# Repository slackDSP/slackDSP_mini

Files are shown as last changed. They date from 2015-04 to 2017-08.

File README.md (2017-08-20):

# slackDSP_mini

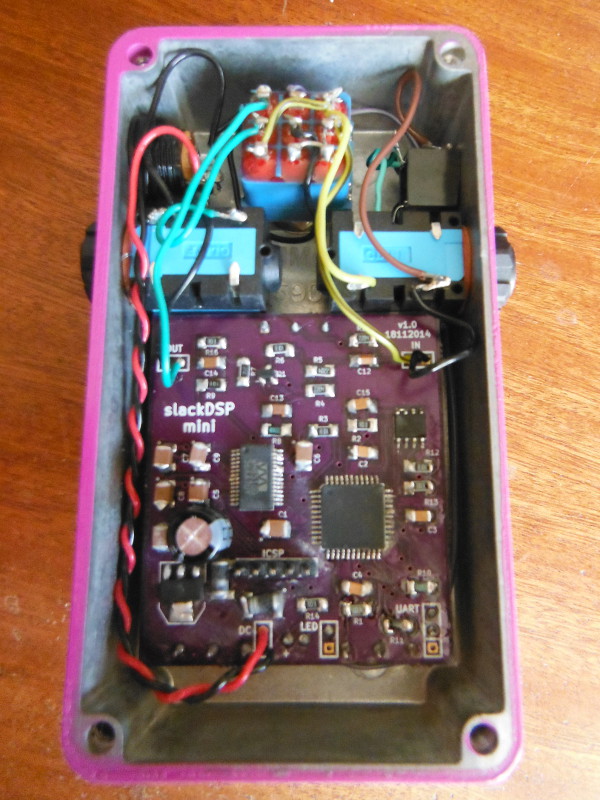
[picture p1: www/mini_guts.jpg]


[YouTube demo video](http://www.youtube.com/watch?v=F_a12EcQlmA)

Nothing to see here yet....

<br>

### Resources
* [dsPIC33FJ128GP804 datasheet](http://ww1.microchip.com/downloads/en/DeviceDoc/70292G.pdf)
* [Wolfson WM8510 datasheet](https://www.cirrus.com/en/pubs/proDatasheet/WM8510_v4.5.pdf)
* [23LC1024 datasheet](http://ww1.microchip.com/downloads/en/DeviceDoc/20005142C.pdf)
* [MPLABX IDE download page](http://www.microchip.com/pagehandler/en-us/family/mplabx/home.html)
* [XC16 compiler download page](http://www.microchip.com/pagehandler/en-us/devtools/mplabxc/home.html)

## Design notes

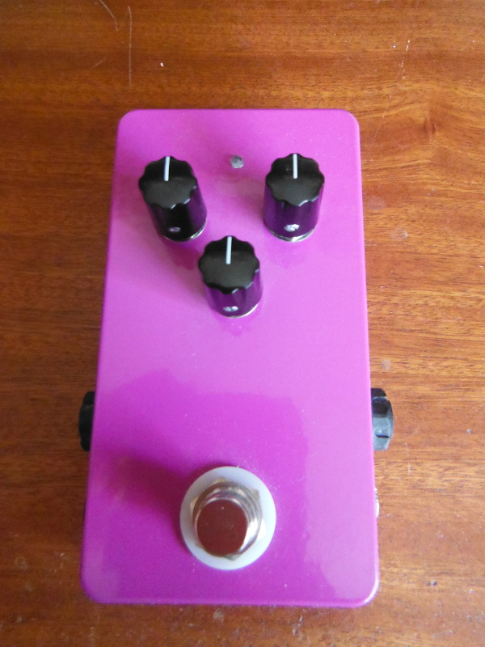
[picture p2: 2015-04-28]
www/mini.jpg

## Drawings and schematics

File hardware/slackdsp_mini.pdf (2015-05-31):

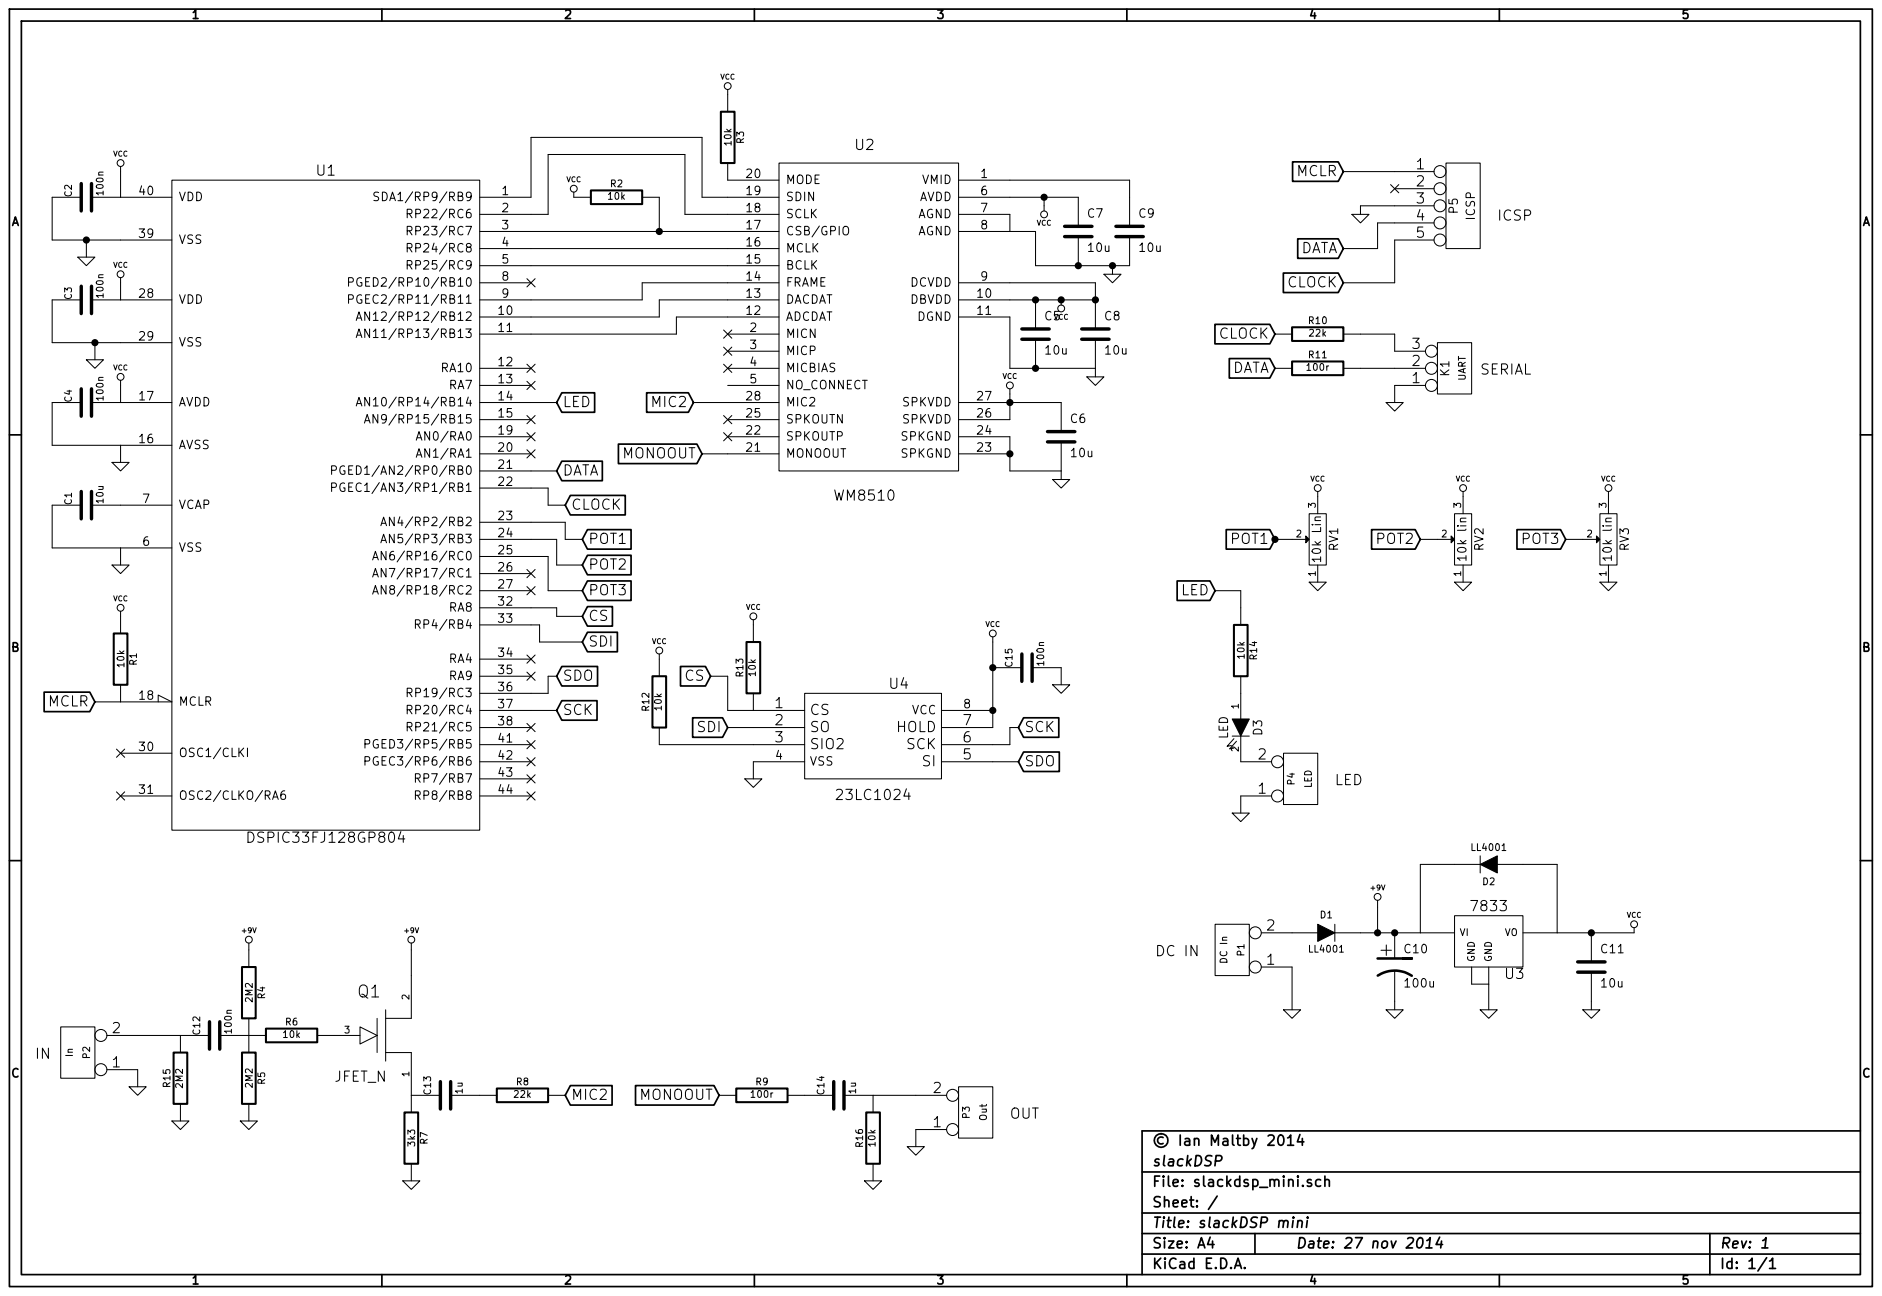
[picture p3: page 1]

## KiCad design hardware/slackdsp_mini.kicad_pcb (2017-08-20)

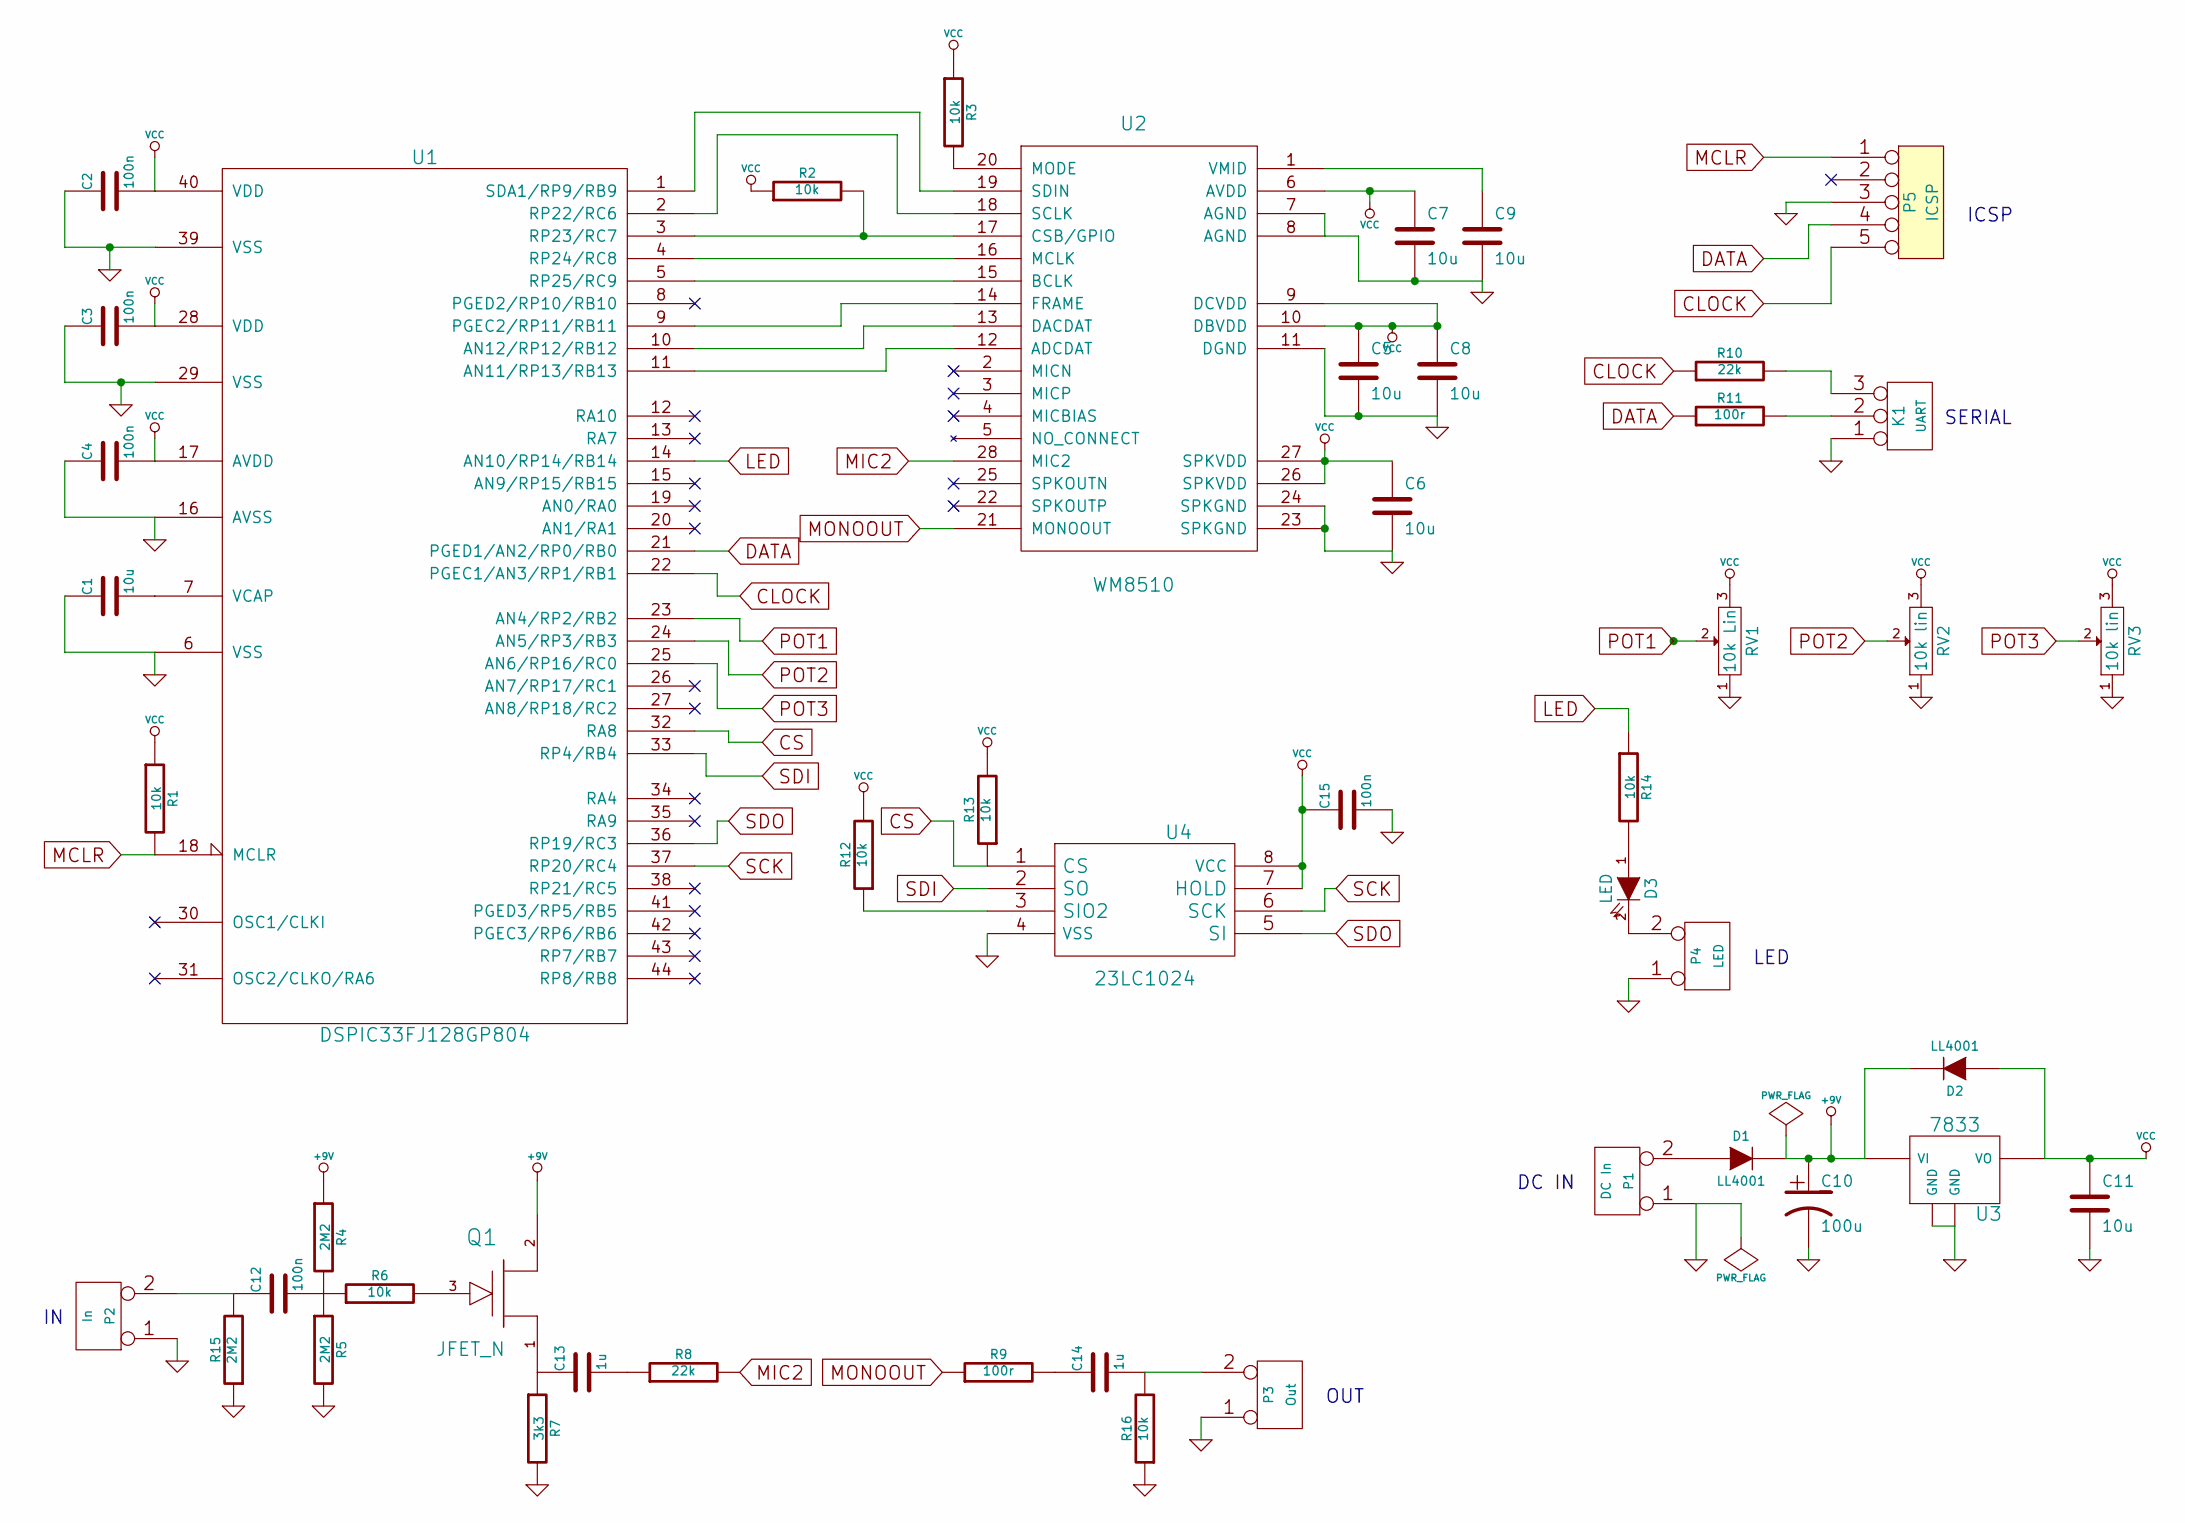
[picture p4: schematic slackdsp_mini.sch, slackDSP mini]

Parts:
C1, C5, C6, C7, C8, C9, C11: 10u; C_1210_HandSoldering
C2, C3, C4, C12, C15: 100n; C_1206
C10: 100u; CP_Radial_D5.0mm_P2.50mm
C13, C14: 1u; C_1206
D1, D2: LL4001; C_1812
D3: LED; LED_D3.0mm
K1: UART; Pin_Header_Straight_1x03_Pitch2.54mm
P1: DC In; Pin_Header_Straight_1x02_Pitch2.54mm
P2: In; Pin_Header_Straight_1x02_Pitch2.54mm
P3: Out; Pin_Header_Straight_1x02_Pitch2.54mm
P4: LED; Pin_Header_Straight_1x02_Pitch2.54mm
P5: ICSP; Pin_Header_Straight_1x05_Pitch2.54mm
Q1: JFET_N; SOT-23
R1, R2, R3, R6, R12, R13, R14, R16: 10k; R_1206
R4, R5, R15: 2M2; R_1206
R7: 3k3; R_1206
R8, R10: 22k; R_1206
R9, R11: 100r; R_1206
RV1: 10k Lin; POT_16mm
RV2, RV3: 10k lin; POT_16mm
U1: DSPIC33FJ128GP804; TQFP-44_10x10mm_Pitch0.8mm
U2: WM8510; SSOP-28_5.3x10.2mm_Pitch0.65mm
U3: 7833; SOT-223
U4: 23LC1024; SO8-Narrow

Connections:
+9V: C10.1, D1.2 (K), D2.2 (K), Q1.2 (D), R4.1, U3.1 (VI)
CLOCK: P5.5, R10.1, U1.22 (PGEC1/AN3/RP1/RB1)
CS: R13.1, U1.32 (RA8), U4.1 (CS)
DATA: P5.4, R11.1, U1.21 (PGED1/AN2/RP0/RB0)
GND: C1.1, C2.1, C3.1, C4.1, C5.2, C6.2, C7.2, C8.2, C9.2, C10.2, C11.2, C15.2, K1.1, P1.1, P2.1, P3.1, P4.1, P5.3, R5.2, R7.2, R15.1, R16.1, RV1.1, RV2.1, RV3.1, U1.6 (VSS), U1.16 (AVSS), U1.29 (VSS), U1.39 (VSS), U2.7 (AGND), U2.8 (AGND), U2.11 (DGND), U2.23 (SPKGND), U2.24 (SPKGND), U3.2 (GND), U3.4 (GND), U4.4 (VSS)
LED: R14.1, U1.14 (AN10/RP14/RB14)
MCLR: P5.1, R1.2, U1.18 (MCLR)
MIC2: R8.2, U2.28 (MIC2)
MONOOUT: R9.1, U2.21 (MONOOUT)
unnamed: C1.2, U1.7 (VCAP)
unnamed: C9.1, U2.1 (VMID)
unnamed: C12.1, P2.2 (PM), R15.2
unnamed: C12.2, R4.2, R5.1, R6.1
unnamed: C13.1, Q1.1 (S), R7.1
unnamed: C13.2, R8.1
unnamed: C14.1, R9.2
unnamed: C14.2, P3.2 (PM), R16.2
unnamed: D1.1 (A), P1.2 (PM)
unnamed: D3.1 (A), R14.2
unnamed: D3.2 (K), P4.2 (PM)
unnamed: K1.2 (PM), R11.2
unnamed: K1.3, R10.2
unnamed: Q1.3 (G), R6.2
unnamed: R2.2, U1.3 (RP23/RC7), U2.17 (CSB/GPIO)
unnamed: R3.2, U2.20 (MODE)
unnamed: R12.1, U4.3 (SIO2)
unnamed: U1.1 (SDA1/RP9/RB9), U2.19 (SDIN)
unnamed: U1.2 (RP22/RC6), U2.18 (SCLK)
unnamed: U1.4 (RP24/RC8), U2.16 (MCLK)
unnamed: U1.5 (RP25/RC9), U2.15 (BCLK)
unnamed: U1.9 (PGEC2/RP11/RB11), U2.14 (FRAME)
unnamed: U1.10 (AN12/RP12/RB12), U2.13 (DACDAT)
unnamed: U1.11 (AN11/RP13/RB13), U2.12 (ADCDAT)
POT1: RV1.2, U1.23 (AN4/RP2/RB2)
POT2: RV2.2, U1.24 (AN5/RP3/RB3)
POT3: RV3.2, U1.25 (AN6/RP16/RC0)
SCK: U1.37 (RP20/RC4), U4.6 (SCK)
SDI: U1.33 (RP4/RB4), U4.2 (SO)
SDO: U1.36 (RP19/RC3), U4.5 (SI)
VCC: C2.2, C3.2, C4.2, C5.1, C6.1, C7.1, C8.1, C11.1, C15.1, D2.1 (A), R1.1, R2.1, R3.1, R12.2, R13.2, RV1.3, RV2.3, RV3.3, U1.17 (AVDD), U1.28 (VDD), U1.40 (VDD), U2.6 (AVDD), U2.9 (DCVDD), U2.10 (DBVDD), U2.26 (SPKVDD), U2.27 (SPKVDD), U3.3 (VO), U4.7 (HOLD), U4.8 (VCC)

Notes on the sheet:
ICSP
SERIAL
OUT
DC IN
LED

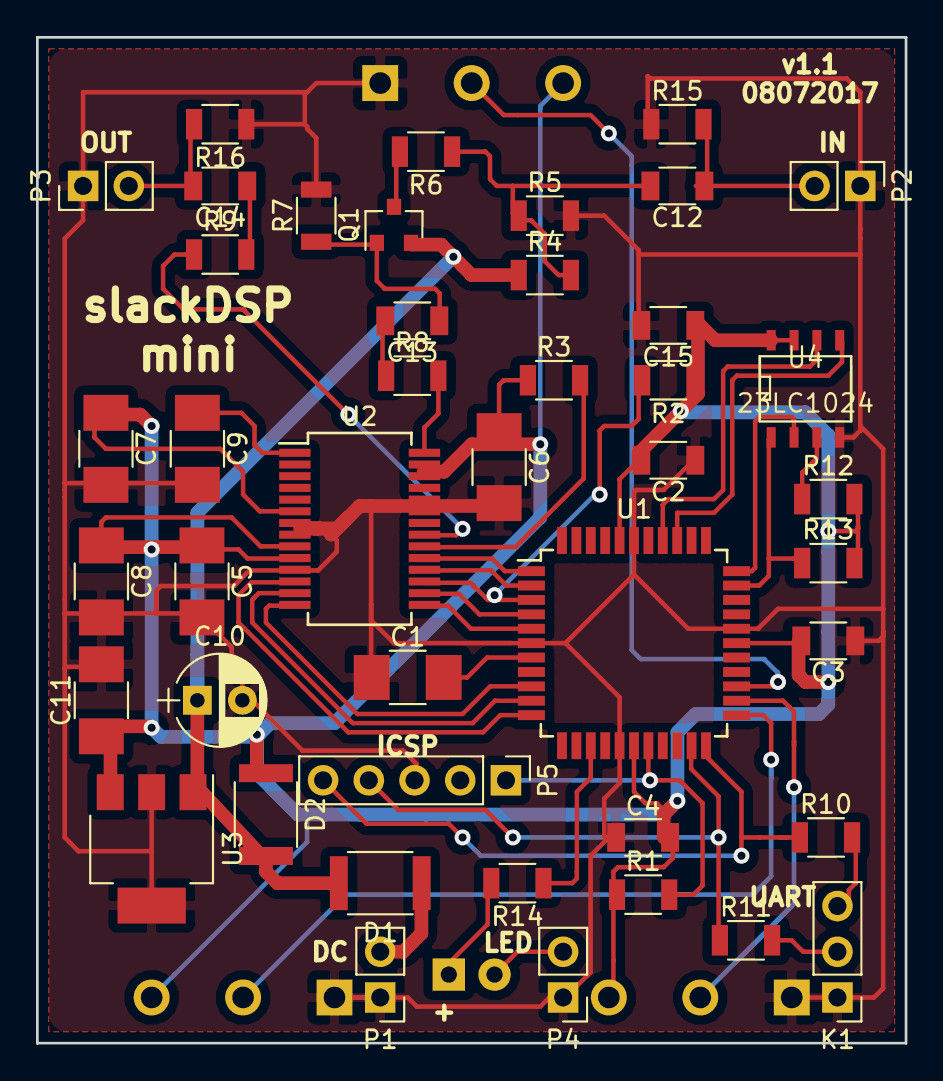
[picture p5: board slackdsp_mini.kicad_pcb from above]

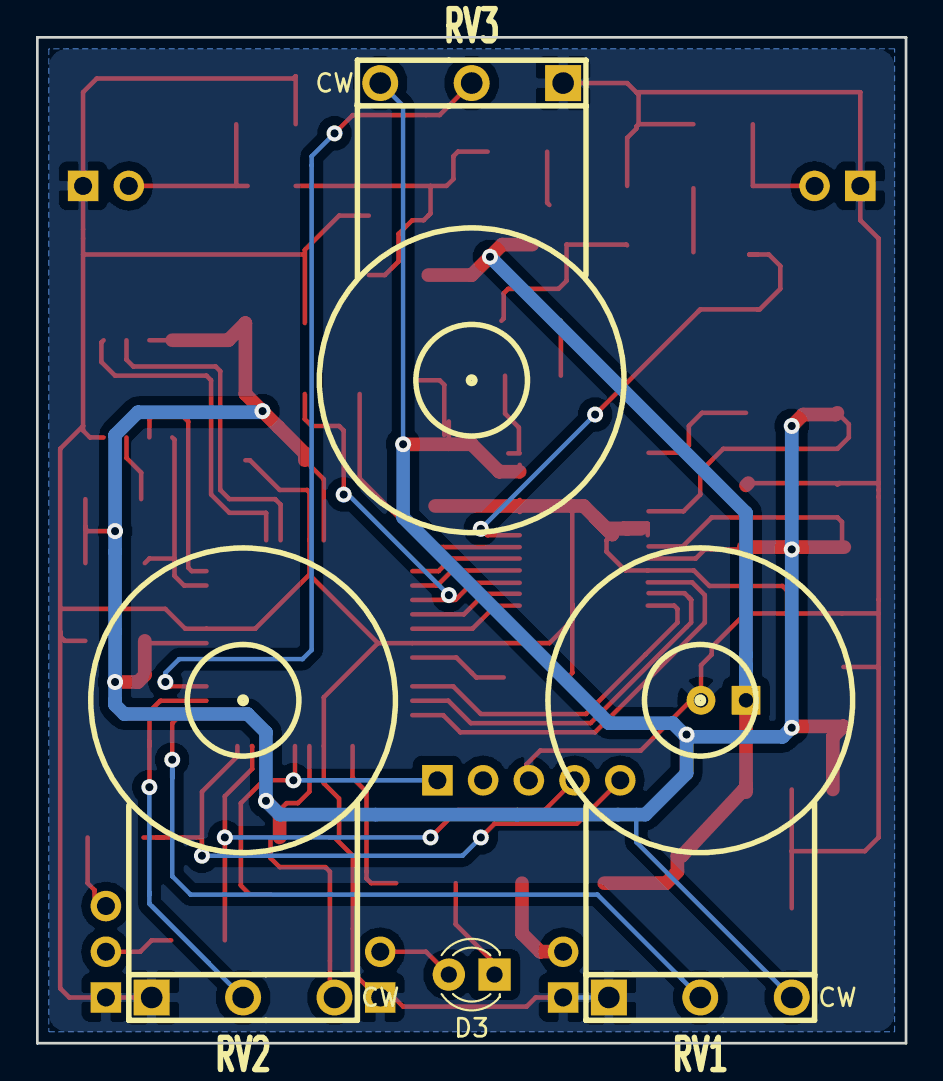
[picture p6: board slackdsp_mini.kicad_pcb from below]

Board: 2 copper layers, 48.3 x 55.9 mm, 48 parts (4 on the bottom side), 40 nets.

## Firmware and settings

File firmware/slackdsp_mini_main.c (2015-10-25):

/*
 *File:   slackdsp_mini_main.c
 *
 *   Copyright © 2015 Ian Maltby
 * This work is free. You can redistribute it and/or modify it under the
 * terms of the Do What The Fuck You Want To Public License, Version 2,
 * as published by Sam Hocevar. See the COPYING file for more details.
 */


#include <xc.h>
#include <stdio.h>
#include <stdlib.h>
#include "dspic_hardware_definitions.h"
#include "WM8510.h"          //include WM8510 library
#include "sram.h"        //inlcude 23LC1024 library
#include "slackdsp_mini.h"   //include slackdsp library

// DSPIC33FJ128GP804 Configuration Bit Settings

// FBS
#pragma config BWRP = WRPROTECT_OFF     // Boot Segment Write Protect (Boot Segment may be written)
#pragma config BSS = NO_FLASH           // Boot Segment Program Flash Code Protection (No Boot program Flash segment)
#pragma config RBS = NO_RAM             // Boot Segment RAM Protection (No Boot RAM)

// FSS
#pragma config SWRP = WRPROTECT_OFF     // Secure Segment Program Write Protect (Secure segment may be written)
#pragma config SSS = NO_FLASH           // Secure Segment Program Flash Code Protection (No Secure Segment)
#pragma config RSS = NO_RAM             // Secure Segment Data RAM Protection (No Secure RAM)

// FGS
#pragma config GWRP = OFF               // General Code Segment Write Protect (User program memory is not write-protected)
#pragma config GSS = OFF                // General Segment Code Protection (User program memory is not code-protected)

// FOSCSEL
#pragma config FNOSC = FRCPLL           // Oscillator Mode (Internal Fast RC (FRC) w/ PLL)
#pragma config IESO = OFF               // Internal External Switch Over Mode (Start-up device with user-selected oscillator source)

// FOSC
#pragma config POSCMD = NONE            // Primary Oscillator Source (Primary Oscillator Disabled)
#pragma config OSCIOFNC = ON            // OSC2 Pin Function (OSC2 pin has digital I/0 function)
#pragma config IOL1WAY = OFF            // Peripheral Pin Select Configuration (Allow Multiple Re-configurations)
#pragma config FCKSM = CSDCMD           // Clock Switching and Monitor (Both Clock Switching and Fail-Safe Clock Monitor are disabled)

// FWDT
#pragma config WDTPOST = PS32768        // Watchdog Timer Postscaler (1:32,768)
#pragma config WDTPRE = PR128           // WDT Prescaler (1:128)
#pragma config WINDIS = OFF             // Watchdog Timer Window (Watchdog Timer in Non-Window mode)
#pragma config FWDTEN = OFF             // Watchdog Timer Enable (Watchdog timer enabled/disabled by user software)

// FPOR
#pragma config FPWRT = PWR128           // POR Timer Value (128ms)
#pragma config ALTI2C = OFF             // Alternate I2C  pins (I2C mapped to SDA1/SCL1 pins)

// FICD
#pragma config ICS = PGD1               // Comm Channel Select (Communicate on PGC1/EMUC1 and PGD1/EMUD1)
#pragma config JTAGEN = OFF             // JTAG Port Enable (JTAG is Disabled)

int main(int argc, char** argv) {

    //setup internal clock for 80MHz/40MIPS using internal fast osc and PLL
    //7.37Mhz / 3 * 65 / 2 = 79.841666Mhz
    CLKDIVbits.PLLPRE = 1; //N1 = 3
    PLLFBD = 63; //M = 65
    CLKDIVbits.PLLPOST = 0; //N2 = 2
    while (!OSCCONbits.LOCK); //wait until PLL is locked

    //Setup IO pins
    AD1PCFGL = 0xFFFF; //set all pins digital
    RPO24 = OC2_out; //RP24 (pin 4) = PWM CLOCKOUT
    RPO9 = SDO1_out; //RP5 (pin 14) = SDO1
    RPO22 = SCK1_out; //RP6 (pin 15) = SCK1
    TRISCbits.TRISC7 = 0; //RC7 (Pin 16) = output = WM8510_SS (SPI slave select)
    RPO19 = SDO2_out; //RP19 (pin 36) = SDO2
    RPO20 = SCK2_out; //RP20 (pin 27) = SCK2
    SDI2_in = RPI4; //RP4 (pin 33) = SDI2
    TRISAbits.TRISA8 = 0; //RA8 (Pin 32) = output = sram_SS (SPI slave select)
    CSCK_in = RPI25; //RP9 (pin 18) = CSCLK << BCLCK
    COFS_in = RPI11; //RP10 (pin 21) = COFS << FRAME
    CSDI_in = RPI13; //RP12 (pin 23) = CSDI << ADCDAT
    RPO12 = CSDO_out; //RP11 (pin 22) = CSDO >> DACDAT

    TRISBbits.TRISB14 = 0;
    AD1PCFGLbits.PCFG4 = 0; //Set AN4 (pin 23) analogue = POT1
    AD1PCFGLbits.PCFG5 = 0; //Set AN5 (pin 24) analogue = POT2
    AD1PCFGLbits.PCFG6 = 0; //Set AN6 (pin 25) analogue = POT3

    //Initialise DCI module
    DCICON1bits.CSCKD = 1; //CSCK is an input
    DCICON1bits.COFSD = 1; //COFS is an input
    DCICON1bits.COFSM = 1; //I2S frame sync
    DCICON1bits.CSCKE = 1; //sample on rising edge
    DCICON1bits.DJST = 0; //data transmission starts 1 clock after frame
    DCICON2bits.BLEN = 3; //4 data words buffered between interrupts
    DCICON2bits.COFSG = 1; //data frame has 2 words
    DCICON2bits.WS = 15; //word data size is 16 bits
    TSCON = 3; //transmit in time slots 0 and 1
    RSCON = 3; //receive in time slots 0 and 1
    DCICON3 = 0;
    IPC15bits.DCIIP = 6; //Set DCI interrupt priority
    IFS3bits.DCIIF = 0; //clear DCI interrupt
    IEC3bits.DCIIE = 1; //enable DCI interrupt
    DCICON1bits.DCIEN = 1; //module enabled
    //DCICON1bits.DLOOP = 1; //loopback

    //Initialise output compare module 1 for PWM output (CLOCKOUT)
    OC1CONbits.OCM = 0; //disable module
    OC1R = 2; //default duty cycle
    OC1CONbits.OCTSEL = 0; //Select timer 2 as time base
    OC1CONbits.OCM = 0b110; //Select output mode PWM

    //Setup ADC module
    AD1CON2bits.VCFG = 0; //Ref = AVDD and AVSS
    AD1CON3bits.ADRC = 0; // Use system timer
    AD1CON3bits.ADCS = 2; //TAD = 3 * TCY
    AD1CON2bits.CHPS = 0; //Convert channel 0
    AD1CHS0bits.CH0SA = 4; //use AN4
    AD1CON1bits.ASAM = 1; //Auto sample
    AD1CON1bits.SSRC = 0; //manual convert
    AD1CON1bits.AD12B = 1; //12 bit sampling
    AD1CON1bits.FORM = 0; //unsigned integer format
    AD1CON1bits.ADON = 1; //ADC On

    //Initialise timer 2 - 10Mhz clock out to drive WM8510
    T2CONbits.TON = 0; //Disable timer
    T2CONbits.TCS = 0; //Select internal instruction cycle clock
    T2CONbits.TGATE = 0; //Disable gated mode
    T2CONbits.TCKPS = 0; //1:1 Prescaler
    TMR2 = 0; //Clear timer register
    PR2 = 3; //Load the period value PWM freq = 10Mhz
    IPC1bits.T2IP = 1; //Set timer 2 priority level
    IFS0bits.T2IF = 0; //Clear timer 2 interrupt flag
    T2CONbits.TON = 1; //Start timer 2

    //Initialise UART1
    U1MODE = 0; //Clear Uart 1 registers
    U1STA = 0; //to tidy up after bootloader
    U1RX_in = RPI1; //RP1 (pin 22) = RX
    RPO0 = U1TX_out; //RP0 (pin 21) = TX
    U1BRG = 259; //set baud rate to 9600
    U1MODEbits.URXINV = 1; //invert RX polarity
    U1STAbits.UTXINV = 1; //invert TX polartity
    IPC2bits.U1RXIP = 7; //set Uart 1 priorty level
    IFS0bits.U1RXIF = 0; //clear RX interrupt
    IFS0bits.U1TXIF = 0; //clear TX interrupt
    IEC0bits.U1RXIE = 1; //Enable RX interrupt
    IEC0bits.U1TXIE = 0; //Disable TX interrupt
    U1MODEbits.UARTEN = 1; //Enable Uart 1
    U1STAbits.UTXEN = 1; //Enable TX

    CLOCKOUT = 2;
    LED = 1;

    WM8510_init(); //initialise WM8510 port
    sram_init(seq); //initialise 23LC1024 in sequential mode

    //Configure WM8510
    WM8510_write(software_reset, 0); //reset
    WM8510_write(power_mngmnt1, 79); //mic2 on, bias on, tie off buffer enabled, vmid 5k
    WM8510_write(power_mngmnt2, 17); //Boost on, ADC on
    WM8510_write(power_mngmnt3, 137); //mono out on, mono mixer on, DAC on
    WM8510_write(input_ctrl, 8); //mic2 = mixer

    //PLL setup to generate 8.192MHz clock for 32kHz sample rate
    WM8510_write(pll_n, 9); //PLL n = 9
    WM8510_write(pll_k1, 53);
    WM8510_write(pll_k2, 74);
    WM8510_write(pll_k3, 280);
    WM8510_write(clock_gen_ctrl, 361); //PLL output, PLL/3, BCCLK/4, Frame master
    WM8510_write(power_mngmnt1, 111); //PLL on

    WM8510_write(audio_interface, 208); //frame clock inverted, word length 24bits, I2S format
    WM8510_write(adc_boost_ctrl, 5); //input boost 0dB
    // WM8510_write(companding_ctrl, 1); //Loopback
    WM8510_write(dac_control, 24); //32kHz de-emphasis, 128x DAC oversample
    WM8510_write(adc_control, 264); //hipass on (removes any audio DC offset), 128x ADC oversample
    WM8510_write(additional_ctrl, 2); //32KHz sample rate
    WM8510_write(mono_mixer_ctrl, 1); //DAC to mono mixer


    for (;;) {

        //do nothing

    }

    return (EXIT_SUCCESS);
}

//DCI ISR

void __attribute__((interrupt, no_auto_psv)) _DCIInterrupt(void) {

    static int dummy = 0;
    static long adc = 0;
    static int sample = 0;
    static int sample1 = 0;
    static int sample2 = 0;
    static long pot_sample = 0;
    static long pots[3] = {0, 0, 0};
    static int pot_select = 0;
    IFS3bits.DCIIF = 0; //clear DCI interrupt

    AD1CON1bits.SAMP = 0;
    while (!AD1CON1bits.DONE);
    AD1CON1bits.DONE = 0;
    pot_sample = ADC;
    if (pot_sample >> 4 == (pot_sample + 4) >> 4)
        pots[pot_select] = (pot_sample << 3) & 32640;

    pot_select++;
    if (pot_select == 3)
        pot_select = 0;

    AD1CHS0bits.CH0SA = pot_select + 4;

    TXBUF0 = sample;
    TXBUF1 = 0;
    TXBUF2 = 0;
    TXBUF3 = 0;

    adc = RXBUF0;
    adc = (adc << 16) | (RXBUF1);
    dummy = RXBUF2;
    dummy = RXBUF3;

    adc = (adc + 32768) >> 16;
    if (adc > 32767)
        adc = 32767;

    sample = adc;

    /*Effect code start*/

    int mode = 0;

    mode = pot3 >> 12;

    if (mode == 0) {

        int apcoeff = 0;
        static long ap1old = 0;
        static long ap1new = 0;
        static long ap2old = 0;
        static long ap2new = 0;
        static long ap3old = 0;
        static long ap3new = 0;
        static long ap4old = 0;
        static long ap4new = 0;
        static long ap5old = 0;
        static long ap5new = 0;
        static long ap6old = 0;
        static long ap6new = 0;
        static long ap7old = 0;
        static long ap7new = 0;
        static long ap8old = 0;
        static long ap8new = 0;
        static int pfeedback;

        apcoeff = 9216 + mulx(tri_lfo(logpot(pot1)), 15488);

        //serial_send(pot2, 16000);

        sample1 = add(sample, mulx(pfeedback,30000));

        ap1new = ((ap1old * apcoeff) >> 15) + sample1;
        sample1 = ((ap1new * -apcoeff) >> 15) + ap1old;
        ap1old = ap1new;

        ap2new = ((ap2old * apcoeff) >> 15) + sample1;
        sample1 = ((ap2new * -apcoeff) >> 15) + ap2old;
        ap2old = ap2new;

        ap3new = ((ap3old * apcoeff) >> 15) + sample1;
        sample1 = ((ap3new * -apcoeff) >> 15) + ap3old;
        ap3old = ap3new;

        ap4new = ((ap4old * apcoeff) >> 15) + sample1;
        sample1 = ((ap4new * -apcoeff) >> 15) + ap4old;
        ap4old = ap4new;

        ap5new = ((ap5old * apcoeff) >> 15) + sample1;
        sample1 = ((ap5new * -apcoeff) >> 15) + ap5old;
        ap5old = ap5new;

        ap6new = ((ap6old * apcoeff) >> 15) + sample1;
        sample1 = ((ap6new * -apcoeff) >> 15) + ap6old;
        ap6old = ap6new;

        ap7new = ((ap7old * apcoeff) >> 15) + sample1;
        sample1 = ((ap7new * -apcoeff) >> 15) + ap7old;
        ap7old = ap7new;

        ap8new = ((ap8old * apcoeff) >> 15) + sample1;
        sample1 = ((ap8new * -apcoeff) >> 15) + ap8old;
        ap8old = ap8new;
        
        pfeedback = mulx((pot2 - 16384) << 1, sample1);
        
        sample = add(sample, sample1);

    }

    if (mode == 1) {

        sample1 = add(sample, mulx(logpot(pot2), sample1));
        sample1 = delayline(131072, pot1 << 2, 0, sample1);
        sample = add(sample, mulx(pot2, sample1));

    }

    if (mode == 2) {

        sample1 = pitchshift(8192, sample);
        sample1 = lowpass(10632, sample1);
        sample2 = pitchshift2(32767, sample);
        sample1 = blend(pot1, sample1, sample2);
        sample = blend(pot2, sample, sample1);

    }

    if (mode == 3) {

        sample = svf((random_lfo(pot1) >> 1) + 2000, pot2, lp, sample);

    }

    if (mode == 4) {

        sample1 = mulx(vco(logpot(pot1) >> 2), sample);
        sample = blend(pot2, sample, sample1);

    }

    if (mode == 5) {

        sample1 = revdelay(131072, pot1 << 2, sample);
        sample = blend(pot2, sample, sample1);

    }

    if (mode == 6) {

#define long_flange 1024
#define short_flange 40
#define flange_range 800
        static int feedback = 0;

        sample1 = add(sample, mulx(feedback, 30000));
        sample1 = delayline(long_flange, short_flange + mulx(hyper_tri_lfo(logpot(pot1)), flange_range), 0, sample1);
        feedback = mulx((pot2 - 16384) << 1, sample1);
        sample = add(sample, sample1);

    }

    if (mode == 7) {

       int scale[8] = {16384, 18390, 20642, 21870, 24548, 27554, 30928, 32767};
      static int pitch = 0;

        pitch = random_lfo(pot1) >> 12;
        sample1 = pitchshift(scale[pitch], sample);
        sample = blend(pot2, sample, sample1);
        
    }

    /*Effect code end*/
}

//UART1 ISR

void __attribute__((interrupt, no_auto_psv)) _U1RXInterrupt(void) {

    const char version[] = "slackDSP mini ("codename")\nBuilt: "__DATE__"\n"; //ignore warning compiles OK
    const char *i;

    IFS0bits.U1RXIF = 0; //clear RX1 interrupt

    if (U1RXREG == 'r') //reset the PIC if "r" is received
        asm("reset");

    if (U1RXREG == 'v') { //print version info if "v" is received
        i = version;
        while (*i) {
            while (U1STAbits.UTXBF);
            U1TXREG = *i;
            i++;
        }
    }
} 

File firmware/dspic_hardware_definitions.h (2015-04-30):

/* 
 * File:   dspic_hardware_definitions.h
 *
 *   Copyright © 2015 Ian Maltby
 * This work is free. You can redistribute it and/or modify it under the
 * terms of the Do What The Fuck You Want To Public License, Version 2,
 * as published by Sam Hocevar. See the COPYING file for more details.
 */

#ifndef DSPIC_HARDWARE_DEFINITIONS_H
#define	DSPIC_HARDWARE_DEFINITIONS_H

//Selectable input sources
#define INT1_in RPINR0bits.INT1R
#define INT2_in RPINR1bits.INT2R
#define T2CK_in RPINR3bits.T2CKR
#define T3CK_in RPINR3bits.T3CKR
#define T4CK_in RPINR4bits.T4CKR
#define T5CK_in RPINR4bits.T5CKR
#define IC1_in RPINR7bits.IC1R
#define IC2_in  RPINR7bits.IC2R
#define IC7_in  RPINR10bits.IC7R
#define IC8_in RPINR10bits.IC8R
#define OCFA_in RPINR11bits.OCFAR
#define U1RX_in RPINR18bits.U1RXR
#define U1CTS_in RPINR18bits.U1CTSR
#define U2RX_in RPINR19bits.U2RXR
#define U2CTS_in RPINR19bits.U2CTSR
#define SDI1_in RPINR20bits.SDI1R
#define SCK1_in RPINR20bits.SCK1R
#define SS1_in RPINR21bits.SS1R
#define SDI2_in RPINR22bits.SDI2R
#define SCK2_in RPINR22bits.SCK2R
#define SS2_in RPINR23bits.SS2R
#define CSDI_in RPINR24bits.CSDIR
#define CSCK_in RPINR24bits.CSCKR
#define COFS_in RPINR25bits.COFSR
#define CIRX_in RPINR26bits.CIRXR

//Output selection for remappable pin (RPn)
#define C1OUT_out 1
#define C2OUT_out 2
#define U1TX_out 3
#define U1RTS_out 4
#define U2TX_out 5
#define U2RTS_out 6
#define SDO1_out 7
#define SCK1_out 8
#define SS1_out 9
#define SDO2_out 10
#define SCK2_out 11
#define SS2_out 12
#define CSDO_out 13
#define CSCK_out 14
#define COFS_out 15
#define C1TX_out 16
#define OC1_out 17
#define OC2_out 18
#define OC3_out 19
#define OC4_out 20

//Peripheral pin inputs
#define RPI0 0
#define RPI1 1
#define RPI2 2
#define RPI3 3
#define RPI4 4
#define RPI5 5
#define RPI6 6
#define RPI7 7
#define RPI8 8
#define RPI9 9
#define RPI10 10
#define RPI11 11
#define RPI12 12
#define RPI13 13
#define RPI14 14
#define RPI15 15
#define RPI16 16
#define RPI17 17
#define RPI18 18
#define RPI19 19
#define RPI20 20
#define RPI21 21
#define RPI22 22
#define RPI23 23
#define RPI24 24
#define RPI25 25

//Peripheral pin outputs
#define RPO0 RPOR0bits.RP0R
#define RPO1 RPOR0bits.RP1R
#define RPO2 RPOR1bits.RP2R
#define RPO3 RPOR1bits.RP3R
#define RPO4 RPOR2bits.RP4R
#define RPO5 RPOR2bits.RP5R
#define RPO6 RPOR3bits.RP6R
#define RPO7 RPOR3bits.RP7R
#define RPO8 RPOR4bits.RP8R
#define RPO9 RPOR4bits.RP9R
#define RPO10 RPOR5bits.RP10R
#define RPO11 RPOR5bits.RP11R
#define RPO12 RPOR6bits.RP12R
#define RPO13 RPOR6bits.RP13R
#define RPO14 RPOR7bits.RP14R
#define RPO15 RPOR7bits.RP15R
#define RPO16 RPOR8bits.RP16
#define RPO17 RPOR8bits.RP17R
#define RPO18 RPOR9bits.RP18R
#define RPO19 RPOR9bits.RP19R
#define RPO20 RPOR10bits.RP20R
#define RPO21 RPOR10bits.RP21R
#define RPO22 RPOR11bits.RP22R
#define RPO23 RPOR11bits.RP23R
#define RPO24 RPOR12bits.RP24R
#define RPO25 RPOR12bits.RP25R

#endif	/* DSPIC_HARDWARE_DEFINES_H */

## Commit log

2015-05-18 renamed folders
    [slackdspic.kicad_pcb, slackdspic.sch]
2015-05-31 Renamed kicad files
    [slackdsp_mini.dsn, slackdsp_mini.kicad_pcb, slackdsp_mini.sch]
2015-05-31 Amended schematic
    [slackdsp_mini.sch]
2015-06-04 Fixed some typos and stuff
    [slackdsp_mini_main.c]
2017-08-20 Updated PCB
    [slackdsp_mini.kicad_pcb, slackdsp_mini.sch]

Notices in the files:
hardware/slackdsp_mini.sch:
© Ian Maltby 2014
